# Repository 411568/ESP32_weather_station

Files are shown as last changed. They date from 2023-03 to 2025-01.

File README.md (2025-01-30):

<p align="center">ESP32_weather_station</p>

<h2>🧐 Features</h2>
This weather station was created as a university project for the "sensor technology" course. It is based on the ESP32 wroom v1 module, connected to several sensors:
 - BME280 - temperature, humidity and pressure sensor
 - BH1750 - illumination sensor
 - diy anemometer
 - YL-83 rain sensor
All of that is powered by a single li-ion 18650 battery, charged with a 2W solar panel through a simple TP4056 module.

The ESP is sending data to the [Thingspeak](https://thingspeak.com) server. We can visualize them using the Python app with PyQT graphs that I also wrote for this project.

The enclousure that you see below was made from plywood cut on a CNC machine. I also placed a piece of plexiglass in front of the solar panel and light sensor to protect them a bit from rain etc.

station picture

<h2>📱 Electronics design</h2>

The electronics design is pretty simple, consisting mostly of ready to use modules, put together on a simple PCB. That is why I am not gonna go ito the details of it.

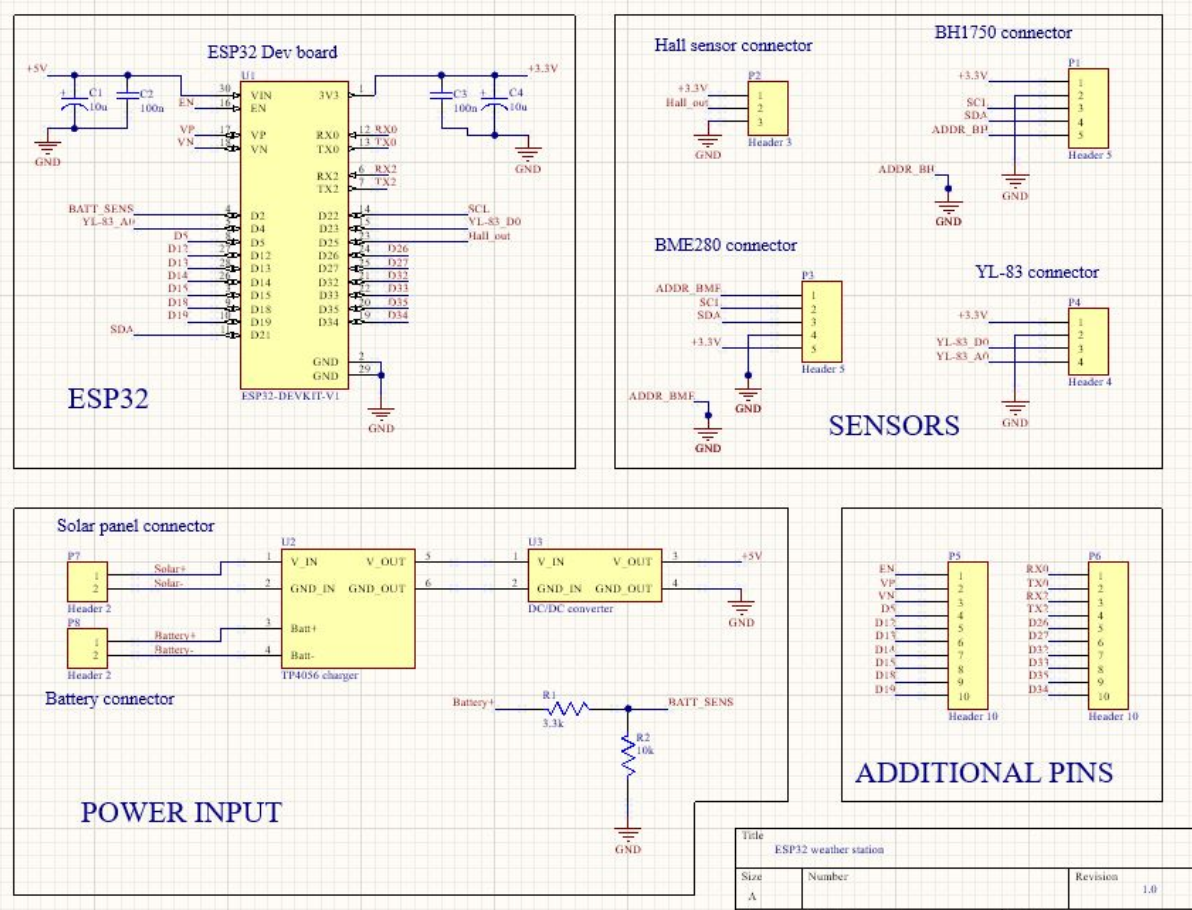
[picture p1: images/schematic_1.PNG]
schematic


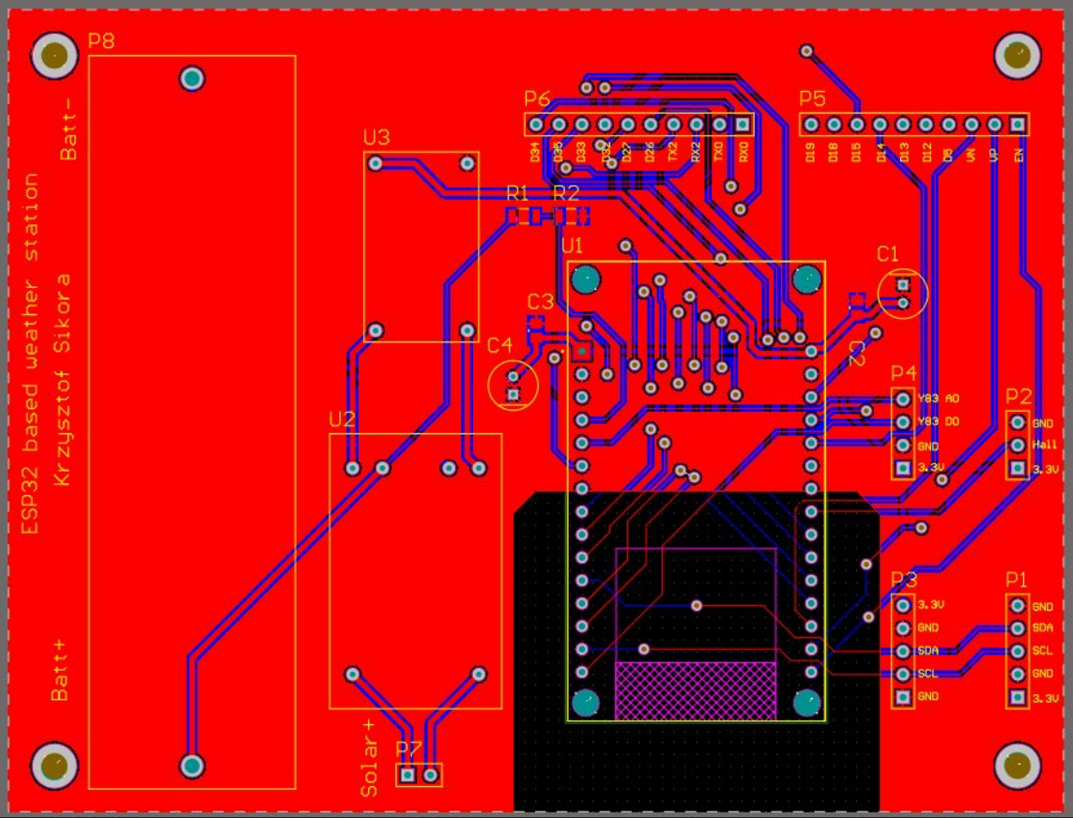
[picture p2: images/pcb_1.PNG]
PCB


<h2>🎐 Diy anemometer</h2>
As the commercially available anemometers are pretty big and expensive I decided to go for a small 3d printed version.

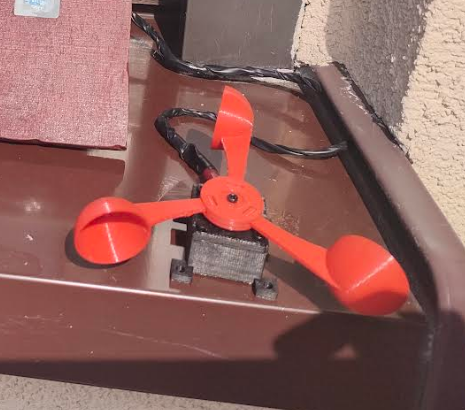
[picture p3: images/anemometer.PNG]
anemometer


To read the wind speed I use a simple digital hall sensor reading the changing magnetic field from the rotating magnes placed on the anemometer shaft. 
Knowing how many times the magnetic field changed in a period of time we calculate the RPM and from that, the wind speed.

<h2>📧 ESP32 code</h2>

All of the ESP32 code was written in Arduino IDE. All of the code is executed in the "setup" section.
At first, the microcontroller connects with all the sensors and start gathering the data.
 ```c
  float temp = get_temperature_reading();
  float humidity = get_humidity_reading();
  float pressure= get_pressure_reading();
  float altitude = get_altitude_reading();
  float light = get_light_reading();
  float rain = get_rain_adc_reading();
  float wind = get_wind_speed_average();
  int battery_level = get_battery_level();
``` 
Then it tries to connect to the wifi network and send the parsed data to the server.
```c
  wifi_setup();
  delay(5000);

  send_data(temp, humidity, pressure, altitude, light, rain, wind, battery_level);
  delay(5000);
```
After it's done that, it goes to sleep for a specified period of time to save battery energy.
 ```c
  esp_sleep_enable_timer_wakeup(TIME_TO_SLEEP * uS_TO_S_FACTOR); //sleep for x minutes
  esp_deep_sleep_start();
 ```

<h2>💻 Python app</h2>

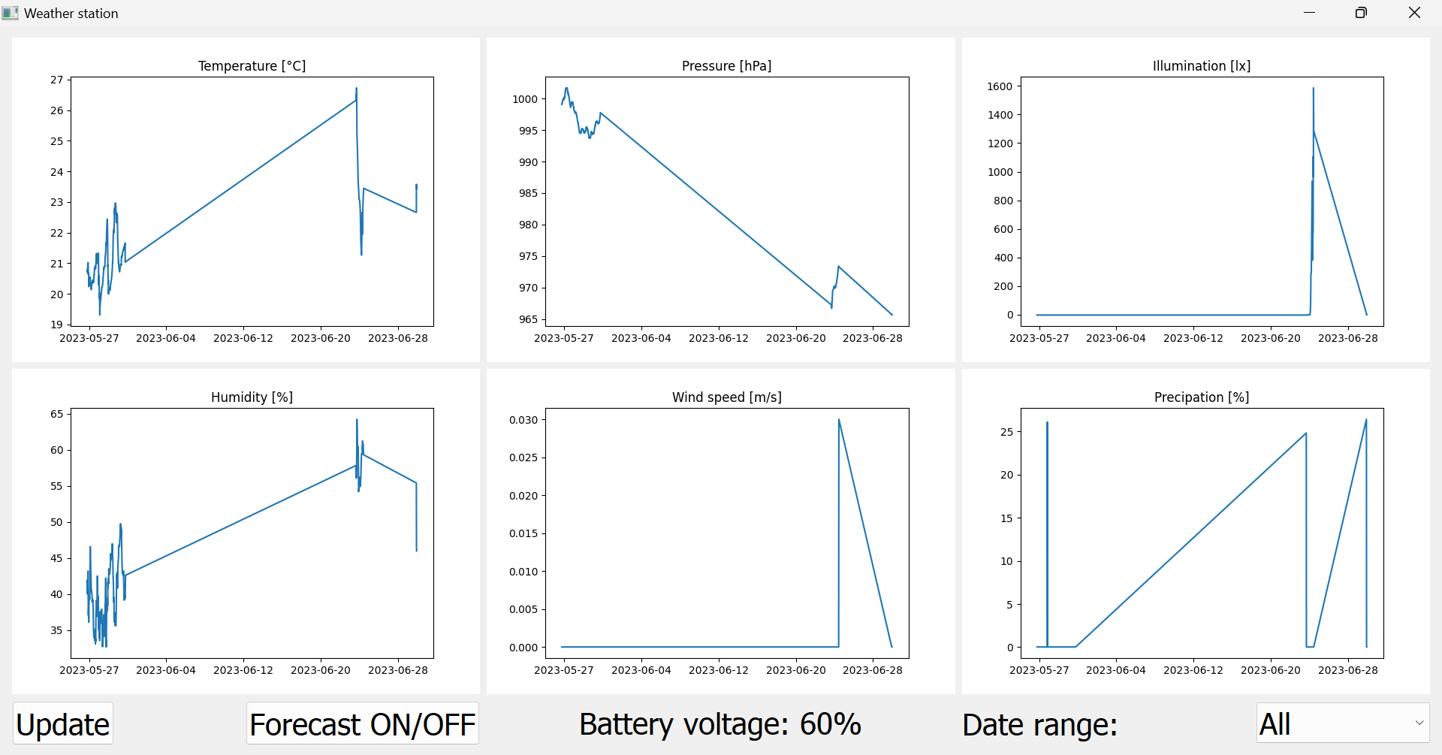
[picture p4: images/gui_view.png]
GUI view


The app you can see in the image above was written in Python using PyQT with matplotlib as GUI. It shows all the basic graphs with data from the Thingspeak server.
In the bottom-right corner you can choose the date range: all, last month, last week, last day. The update button makes the app download all the data again and the forecast button 
turns on the SARIMA forecasting feature. It's using the statsmodel library with it's auto arima function that automatically finds the optimal parameters for the 
statistical model. The forecast is set to take into account the average values for every day and make predictions for the next 10 days (1 for each day). Due to the current lack of consistent data I can't 
guarantee it will work correctly and I might make some adjustments in the future.

If you want to learn more about the SARIMA model I suggest you check out this [YT channel](https://www.youtube.com/@AricLaBarr).

<h2>🛡️ License:</h2>

This project is licensed under the MIT License.

<h2> 🙋‍♂️Authors </h2>

- Krzysztof Sikora

<h2>💖Like my work?</h2>

If you have any questions about the project feel free to contact us via email: krzysieksikora717@gmail.com

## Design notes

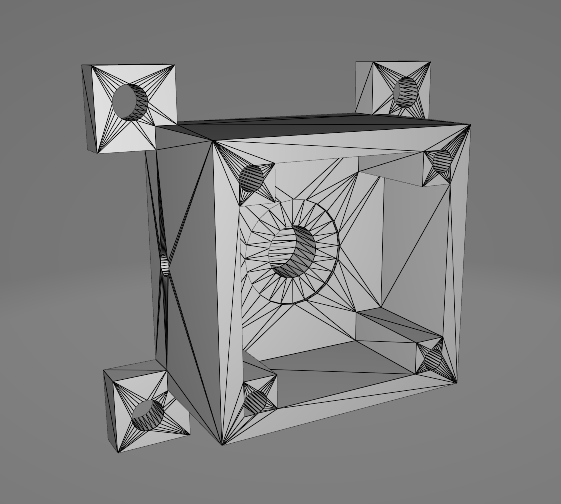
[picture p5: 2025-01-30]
images/anem_1.PNG

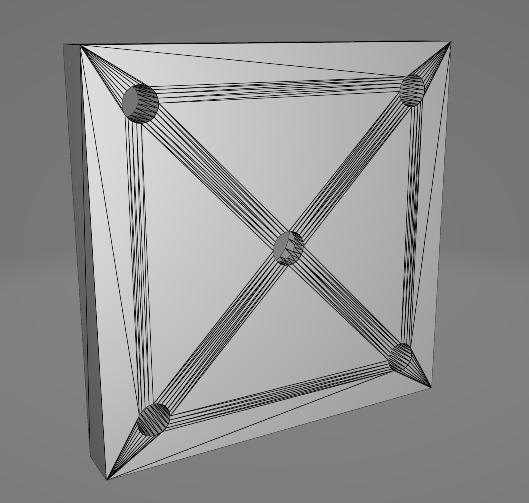
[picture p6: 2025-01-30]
images/anem_2.PNG

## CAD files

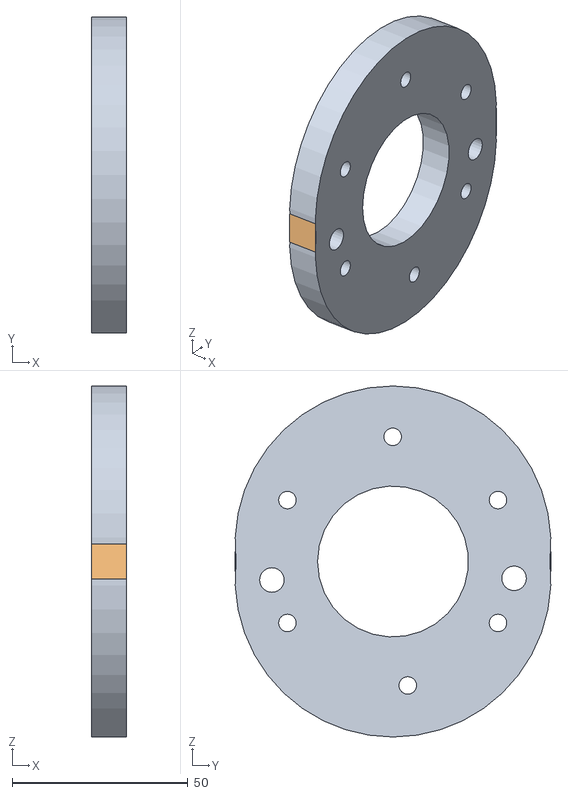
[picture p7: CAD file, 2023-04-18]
3dmodels/seat steering wheel mount v2.obj
10.0 x 90.0 x 100.0

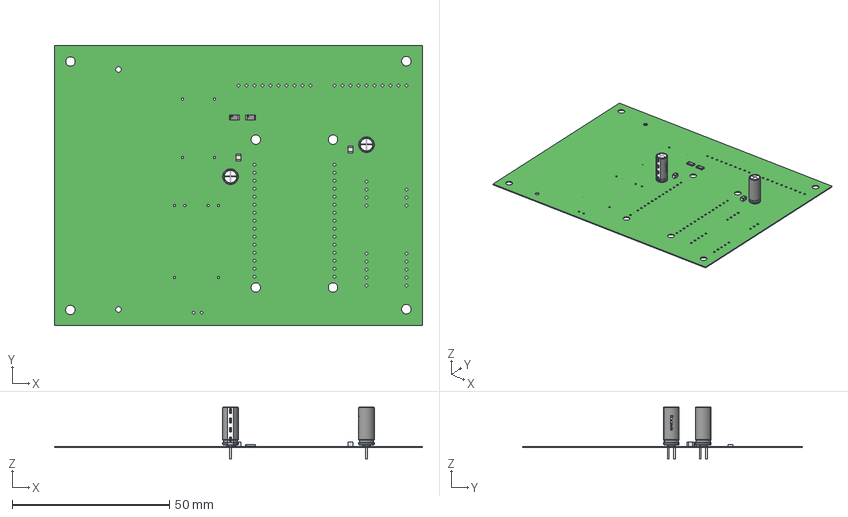
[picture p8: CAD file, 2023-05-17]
ESP32_weather_station/PCB13d.step
116.8 x 88.9 x 16.5 mm
terminals x 2
top x 4
logo x 4
marking x 2
bottom x 2
polarity marking x 2
terminal x 2
Extruded x 6

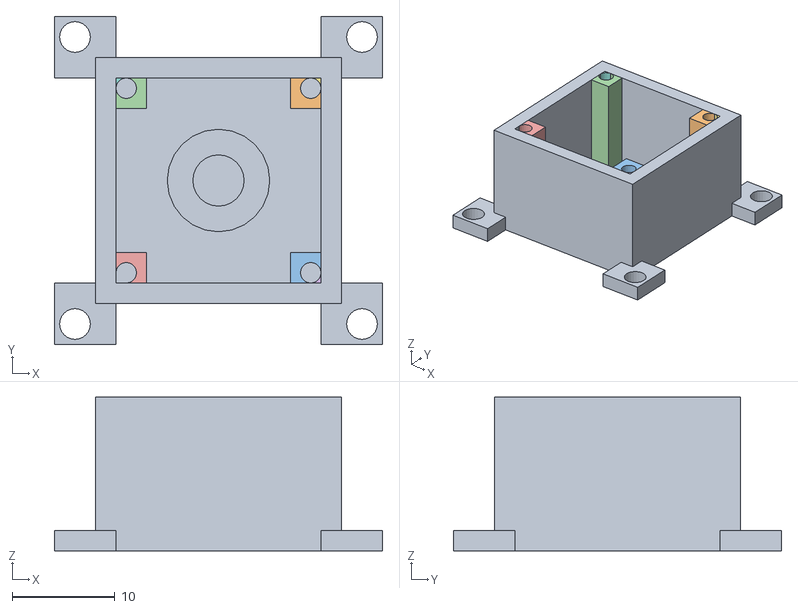
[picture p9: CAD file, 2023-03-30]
3dmodels/bottom v4.obj
32.0 x 32.0 x 15.0

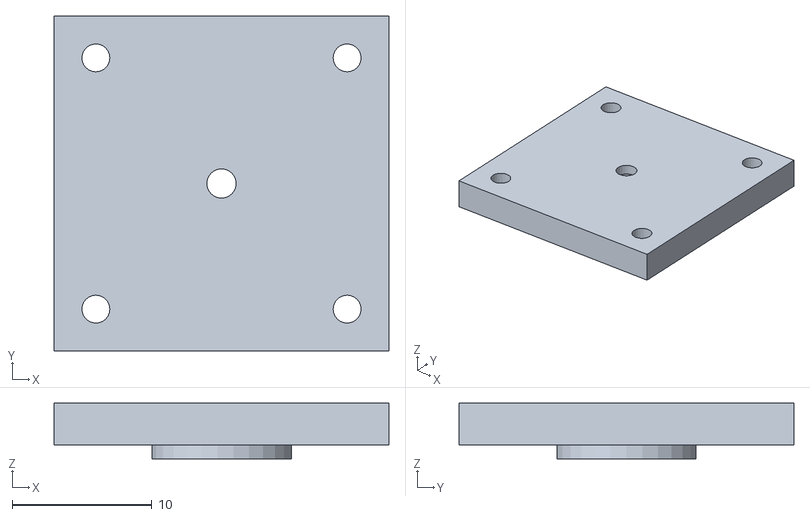
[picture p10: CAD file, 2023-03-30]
3dmodels/top_anem.obj
24.0 x 24.0 x 4.00

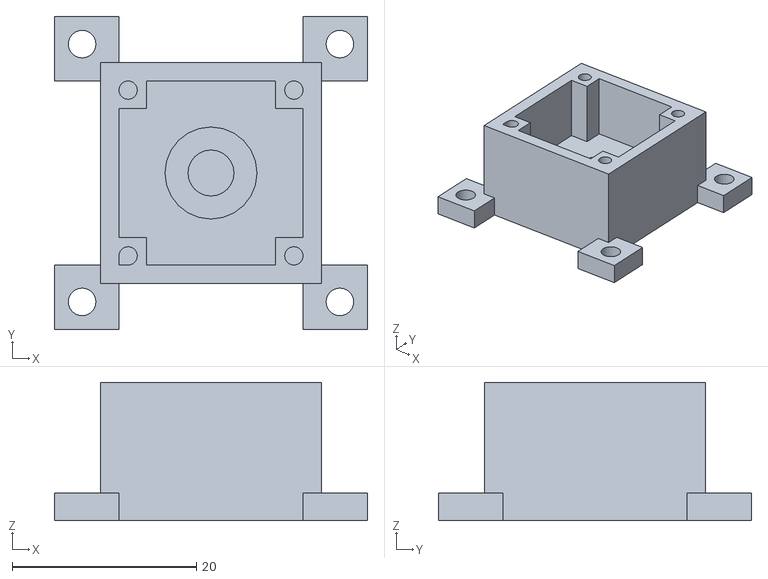
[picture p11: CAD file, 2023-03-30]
3dmodels/anem_box_v2.obj
34.0 x 34.0 x 15.0

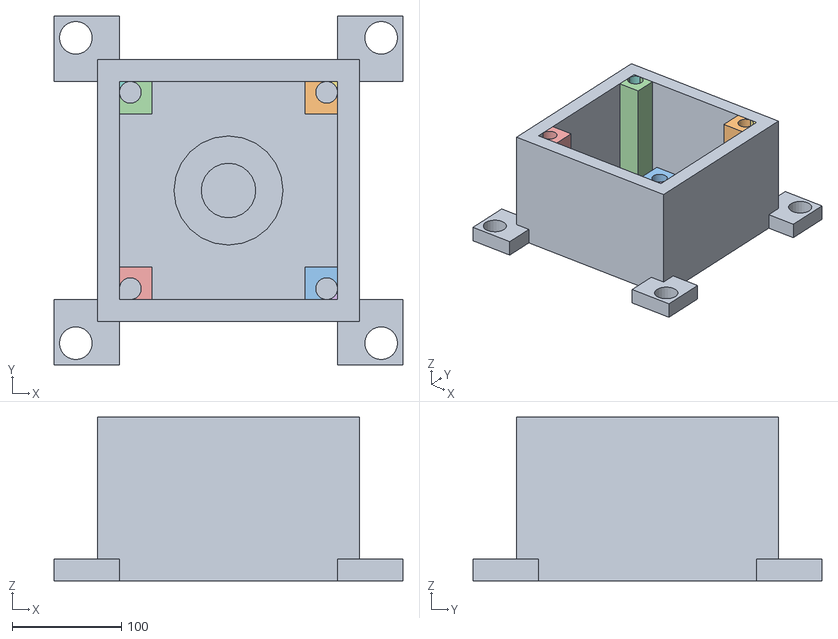
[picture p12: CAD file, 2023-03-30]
3dmodels/anemometer_box.obj
320.0 x 320.0 x 150.0

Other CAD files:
ESP32_weather_station/PCB1v3.step

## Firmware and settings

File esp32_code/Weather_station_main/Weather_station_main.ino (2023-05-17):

// SLEEP TIME
#define uS_TO_S_FACTOR 1000000 /* Conversion factor for micro seconds to seconds */ 
#define TIME_TO_SLEEP 600 /* Time ESP32 will go to sleep (in seconds) */

void setup() 
{
  //setup sensors
  sensor_setup();

  //get sensor readings
  float temp = get_temperature_reading();
  float humidity = get_humidity_reading();
  float pressure= get_pressure_reading();
  float altitude = get_altitude_reading();
  float light = get_light_reading();
  float rain = get_rain_adc_reading();
  float wind = get_wind_speed_average();
  int battery_level = get_battery_level();

  //setup wifi (data logging)
  wifi_setup();
  delay(5000);

  //send data to thingspeak
  send_data(temp, humidity, pressure, altitude, light, rain, wind, battery_level);
  delay(5000);

  Serial.println("Data sent");
  Serial.flush(); 

  //go to sleep
  esp_sleep_enable_timer_wakeup(TIME_TO_SLEEP * uS_TO_S_FACTOR); //sleep for x minutes
  esp_deep_sleep_start();
}

void loop() 
{
  //does nothing in the main loop
}

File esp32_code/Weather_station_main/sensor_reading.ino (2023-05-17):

#include <Wire.h>
#include <BH1750.h>
#include <Adafruit_Sensor.h>
#include <Adafruit_BME280.h>


//used by BME280 for calculating altitude
#define SEALEVELPRESSURE_HPA (1013.25)

//rain sensor analog pin
#define rain_sensor_pin 4

//rain sensor threshold
#define rain_threshold 2000

// hall sensor pin
#define hall_pin 25

// battery level adc pin
#define battery_pin 2

// SENSOR objects
BH1750 lightMeter; // light sensor
Adafruit_BME280 bme;  //temperature, pressure, humidity


void sensor_setup()
{
  //start the I2C
  Wire.begin();

  //initialize the light sensor
  lightMeter.begin();

  //initialize the BME280
  bool status = bme.begin(0x76);  
  if (!status) 
  {
    Serial.begin(9600);
    Serial.println("Could not find a valid BME280 sensor, check wiring!");
    //while (1);
  }

  
  pinMode(hall_pin, INPUT_PULLUP); //hall sensor input


}

// ---------------- BME280 ---------------- //
float get_temperature_reading()
{
  bme.begin(0x76);
  return bme.readTemperature(); // in *C
}


float get_pressure_reading()
{
  bme.begin(0x76);
  return (bme.readPressure() / 100.0F); // in hPa
}

float get_altitude_reading()
{
  bme.begin(0x76);
  return bme.readAltitude(SEALEVELPRESSURE_HPA); // in m
}


float get_humidity_reading()
{
  bme.begin(0x76);
  return bme.readHumidity(); // in %
}



// ---------------- BH1750 ---------------- //
float get_light_reading()
{
  Wire.begin();
  lightMeter.begin();
  return lightMeter.readLightLevel(); //in lux
}



// ---------------- Rain sensor ---------------- //
float get_rain_adc_reading()
{
  int temp = analogRead(rain_sensor_pin);
  float perc_temp = (4096.0 - float(temp)) / 40.96; 
  return perc_temp;
}

bool is_it_raining()
{
  if(get_rain_adc_reading() > rain_threshold)
  {
    return false;
  }
  else
  {
    return true;
  }
}


// ---------------- Battery level ---------------- ///
int get_battery_level()
{
  int battery_adc = analogRead(battery_pin);
  int battery_level = (battery_adc - 2321) / 5.46; //estimate battery percentage level 
  //the calculations above assume the max batt voltage to be 4.2V and lowest 3.4V
  return battery_level;
}


// ---------------- Anemometer ---------------- //
float get_wind_speed_reading()
{
  float hall_thresh = 10.0;
  float hall_count = 0.0;
  float start = micros(); // start the time count
  bool on_state = false;

  // counting number of times the hall sensor is tripped
  // but without double counting during the same trip
  while(true)
  {
    if (digitalRead(hall_pin) == 0)
    {      
      if (on_state==false)
      {
        on_state = true;
        hall_count += 1.0;
      }
    } 
    else
    {
      on_state = false;
    }
    
    //if threshold reached -> break
    if (hall_count >= hall_thresh)
    {
      break;
    }

    //if taking too long to reach th
    if(((micros()-start)/1000000.0) > 5)
    {
      break;
    }    
  }
  
  //calculate rpm
  float end_time = micros();
  float time_passed = ((end_time-start)/1000000.0);
  float rpm_val = (hall_count/time_passed)*60.0;
  //calculate wind speed in m/s
  float wind_speed = 2 * 3.14 * 0.045 * rpm_val / 60; // 0.045 is the arm length (R)
  return wind_speed;
  delay(10);
}

float get_wind_speed_average()
{
  float sum = 0.0;
 
  for(int i = 0; i < 5; i++)
  {
    sum += get_wind_speed_reading();
  }
  
  return sum/5;
}

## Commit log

2023-03-22 added schematic rev 1.0
    [ESP32_weather_station.PrjPcb, esp32_weather_station_schematic_main.SchDoc]
2023-03-22 python app added
    [esp32_weather_station_schematic_main.SchDoc]
2023-03-22 pcb update
    [ESP32_weather_station.PrjPcb, PCB1.PcbDoc, PcbLib1.PcbLib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]
2023-03-27 finished PCB
    [ESP32_weather_station.PrjPcb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]
2023-03-29 esp32 code
2023-03-29 rpm reading
    [ESP32_weather_station.PrjPcb]
2023-03-30 3d models
    [anem_box_v2.obj, anemometer_box.obj, bottom v4.obj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]
2023-04-18 date range change
    [seat steering wheel mount v2.obj]
2023-04-18 battery voltage fix
2023-04-18 battery level fix
2023-05-17 battery and wind speed reading fix
    [PCB1.PcbDoc, PCB13d.step, PCB1v3.step]
